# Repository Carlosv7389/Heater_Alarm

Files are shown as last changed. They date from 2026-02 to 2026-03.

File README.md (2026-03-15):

# Heater Alarm
A small and easy to mount device that turns on a heater in order to warm a room at a specified military time.<br>
Heater Alarm

## Table of Contents
1. [Demo](#demo)
2. [Built With](#built-with)
3. [Installation](#installation)
4. [Getting Started](#getting-started)
5. [Usage](#usage)
6. [License](#license)
7. [Acknowledgments](#acknowledgments)

## Demo
A Youtube Short testing the Heater Alarm can be found here: <br>
Here (https://youtube.com/shorts/zdMKMSuSnVs)

## Built With
IDE: VScode with Platformio extension<br>
MCU: ESP32 wroom wifi devkit V1<br>
Serial Monitoring: Tera Term<br>
Platform: Espressif32<br>
Framework: Adruino<br>

## Installation
* To clone this repository:

    ```bash
    git clone https://github.com/Carlosv7389/Heater_Alarm
    ```

* Download VScode at [this link](https://code.visualstudio.com/download)

    * In the "extension" section find platformio 
    <!-- ![install procedure](Project_Media_files/VScode&Platformio.png) -->
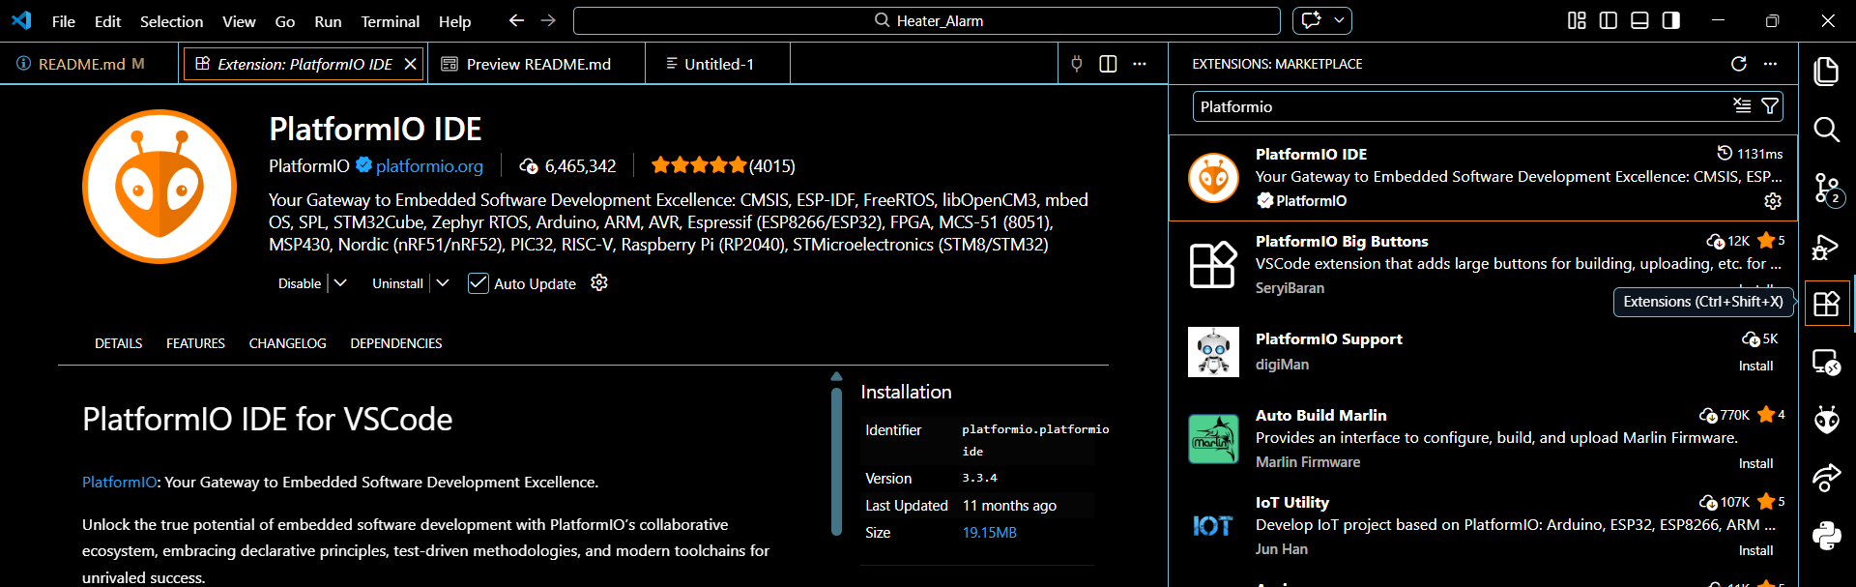
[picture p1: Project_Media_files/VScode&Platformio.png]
Platformio Install screen
    

* Download Tera Term at [this link](https://github.com/TeraTermProject/teraterm/releases)
## Getting Started 
* In VScode, open the folder *Platformio_arduino_wifi*

* Build the circuit shown below:<br>
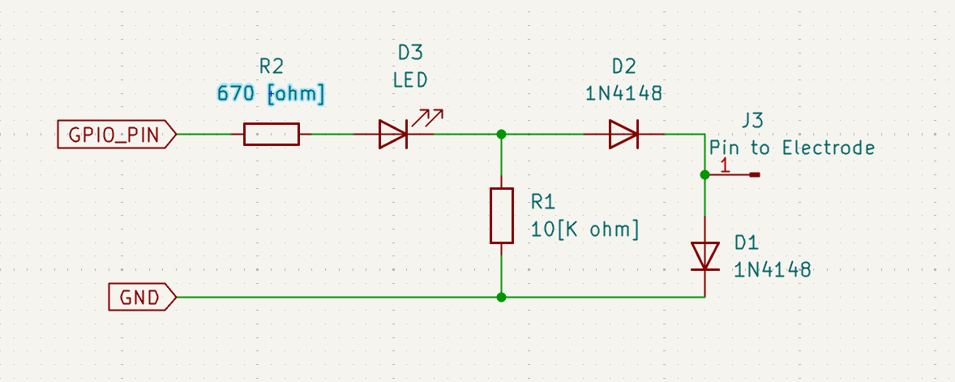
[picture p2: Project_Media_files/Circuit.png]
Capacitive Touch Circuit Schematic
    

* To push the code on to the microcontroller, select all code in *main.cpp* and comment it out. The code from the files in the *lib* folder will be pasted into the bottom of the main file and ran before running the actual main code. <br>

## Usage
* Edit the file *include/secrets.h* to change the ssid and password to your wifi ssid and password.
    ```cpp
    // wifi credentials
    const char *ssid = "change to your SSID";
    const char *password = "change to your password";
    ```

* Check Wifi coverage for your microcontroller by running the code found in *lib/WiFi/WIFIScan.cpp*, run Tera Term and check to see if your WiFi SSID is found in the serial terminal ouput, in the image below, my SSID is "CMCKV9803" and so the device is close enough.<br>
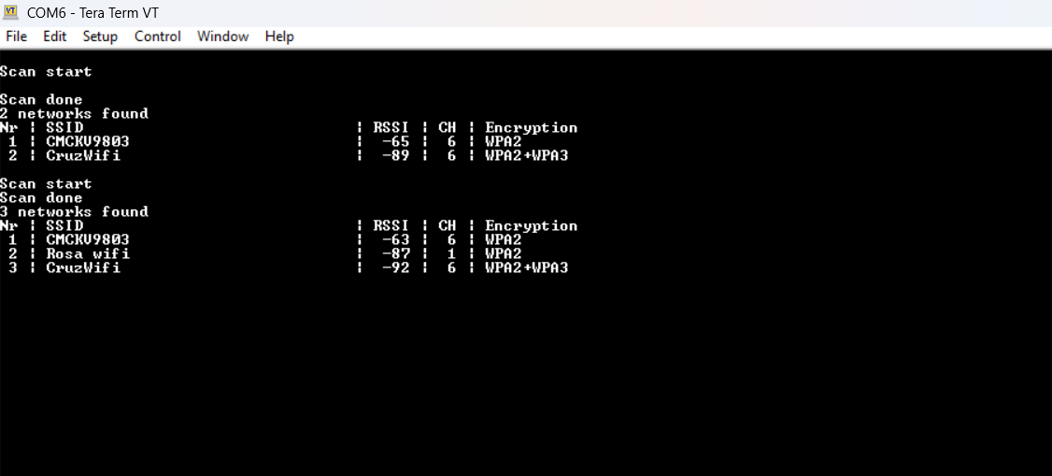
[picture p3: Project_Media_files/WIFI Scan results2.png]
Wifi scan result screen


* Verify circuit by running the code found in *lib/Blink/Blink.cpp*. When the LED transitions from off to on, the heater should turn on as well as seen in the gif below <br>


* Deploy the original code in the *main.cpp* code by uncommenting and changing the main file in order to match your target time, local timezone, and daylight savings offset.
```cpp
const long gmtOffset_sec = (-5)*3600;  // offset for Central Standard Time in seconds (which is "-5 GMT")
const int daylightOffset_sec = 0; // Offset for daylight savings, set to 0 after changing time in spring, set to 3600 when changing time in the fall. 

// Target time to send activation signal (24-hour format) (currently set to 6:45 AM)
const int TARGET_HOUR = 6;    // 6 hours
const int TARGET_MINUTE = 45;  // 45 minutes
const int TARGET_SECOND = 0;   // 0 seconds
```

Tera Term was used as a serial monitor but can't be used simultaneously while uploading code to the microcontroller, make sure its not active when you upload code.
## License
This project is licensed under the MIT License - see the [LICENSE](LICENSE) file for details.

## Acknowledgments
Huge thanks to the channel [Leo's Bag of Tricks](https://www.youtube.com/@leosbagoftricks3732) for making insightful videos on capacitive touch circuits. The circuit shown in the demo is a THT version of the SMD circuit found [here](https://www.youtube.com/watch?v=V0UkCcv2LmQ)

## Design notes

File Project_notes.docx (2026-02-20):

Usefule repo for the ESP32 wroom

ESP32-WROOM-32/esp32-wroom-wifi-devkit-v1_pinout.png at master · devdotnetorg/ESP32-WROOM-32 · GitHub (https://github.com/devdotnetorg/ESP32-WROOM-32/blob/master/esp32-wroom-wifi-devkit-v1_pinout.png)

# Wifi

We either connect to the ESP as an Access point or the ESP connects to the router as a server. For this project we will use esp32 as a server.

From past testing, walls and distance may cause interference in wifi strength, but that does not seem to be an issue for my current configuration.

# RTC

We will use this to keep the time. It will act as a local truth and get updated by an internet clock and we will treat the internet clock as the ground truth

# Low Power Sleep

We will use this module to lower power consumption. The longer we have the sleep, the less reliable the time will be but the trade off is we consume less power

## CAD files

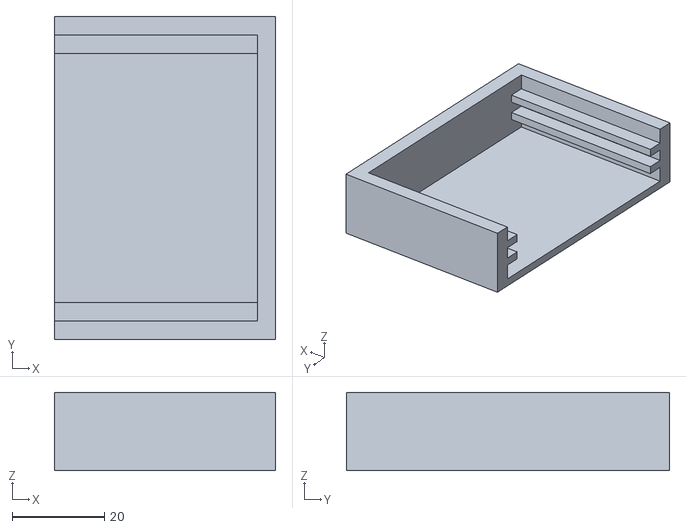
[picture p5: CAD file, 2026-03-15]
CAD Files/EnclosureV3.stl
48.0 x 70.0 x 17.0

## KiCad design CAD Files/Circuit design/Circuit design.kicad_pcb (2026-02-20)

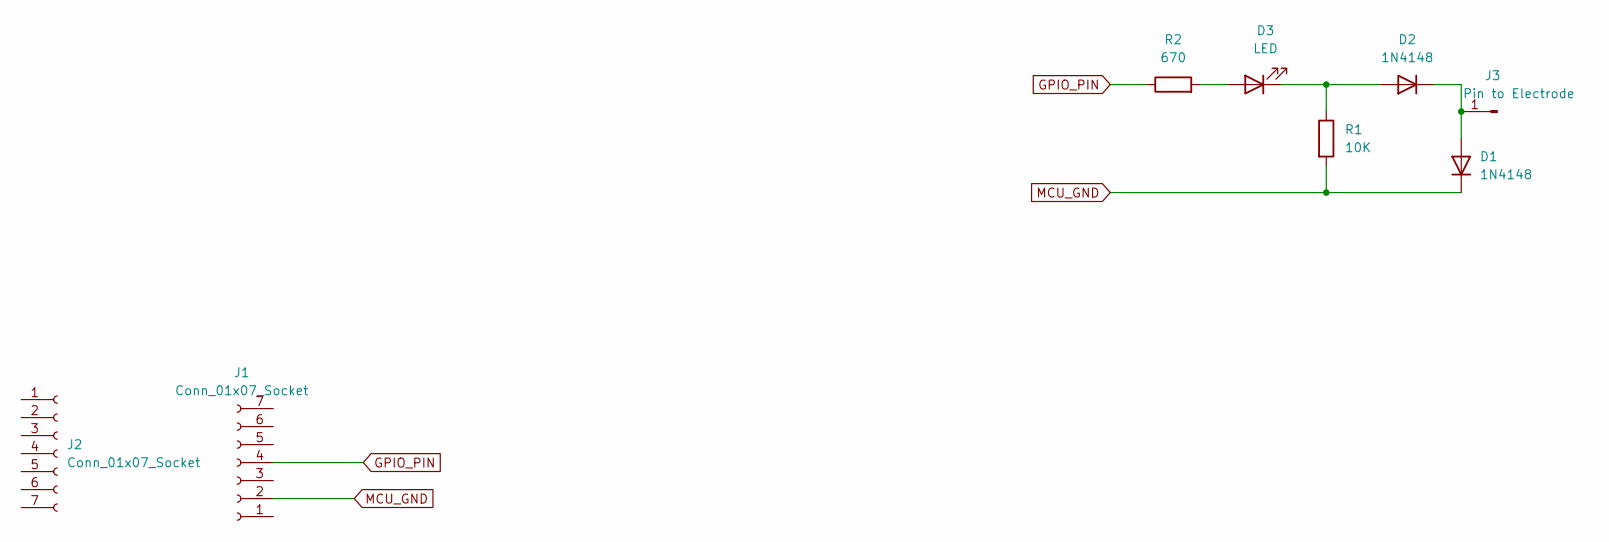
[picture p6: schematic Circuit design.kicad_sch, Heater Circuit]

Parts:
D1, D2: 1N4148; D_DO-35_SOD27_P7.62mm_Horizontal
D3: LED; LED_D3.0mm
J1, J2: Conn_01x07_Socket; PinHeader_1x07_P1.27mm_Vertical
J3: Pin to Electrode; PinHeader_1x01_P1.27mm_Vertical
R1: 10K; R_Axial_DIN0204_L3.6mm_D1.6mm_P5.08mm_Horizontal
R2: 670; R_Axial_DIN0204_L3.6mm_D1.6mm_P5.08mm_Horizontal

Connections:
GPIO_PIN: J1.4, R2.1
MCU_GND: D1.1 (K), J1.2, R1.2
unnamed: D1.2 (A), D2.1 (K), J3.1
unnamed: D2.2 (A), D3.1 (K), R1.1
unnamed: D3.2 (A), R2.2

Board: 2 copper layers, 8 parts (0 on the bottom side), 5 nets, no tracks yet.

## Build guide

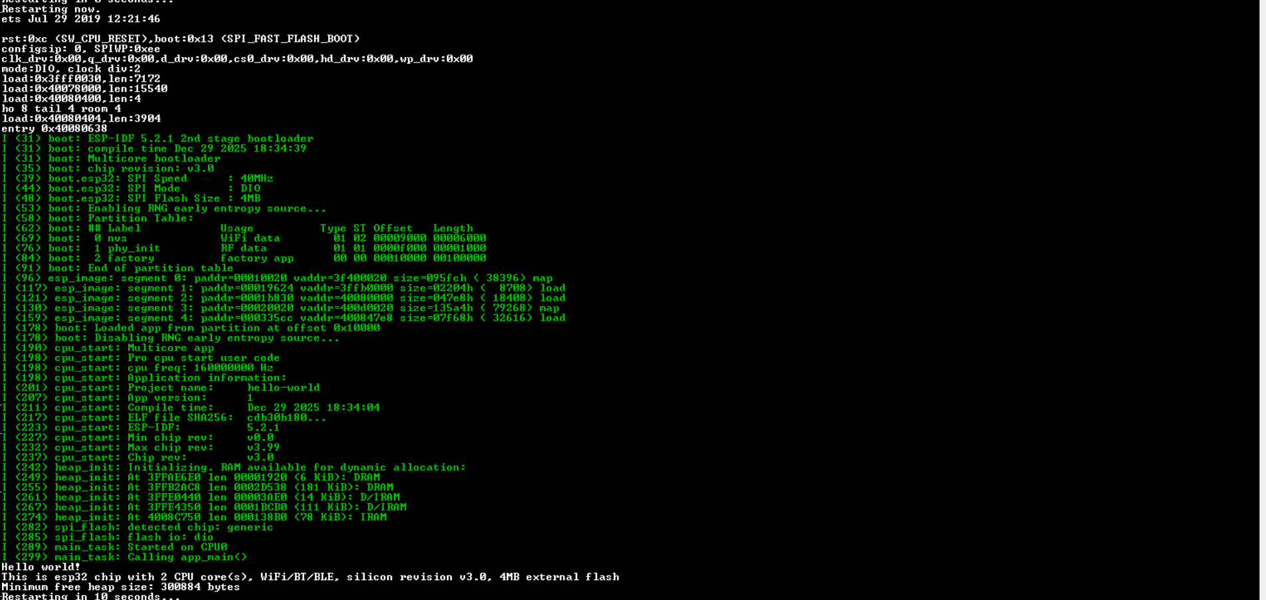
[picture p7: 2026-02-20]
Project_docs/esp32-printout.png

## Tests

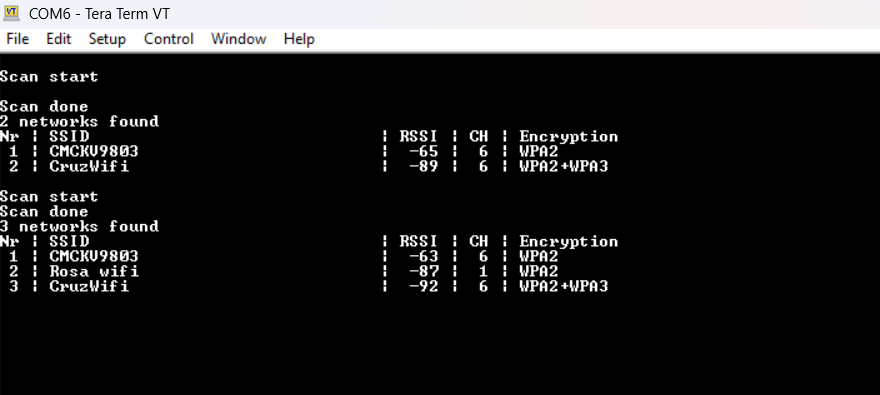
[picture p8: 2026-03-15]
Project_Media_files/WIFI Scan results3.png

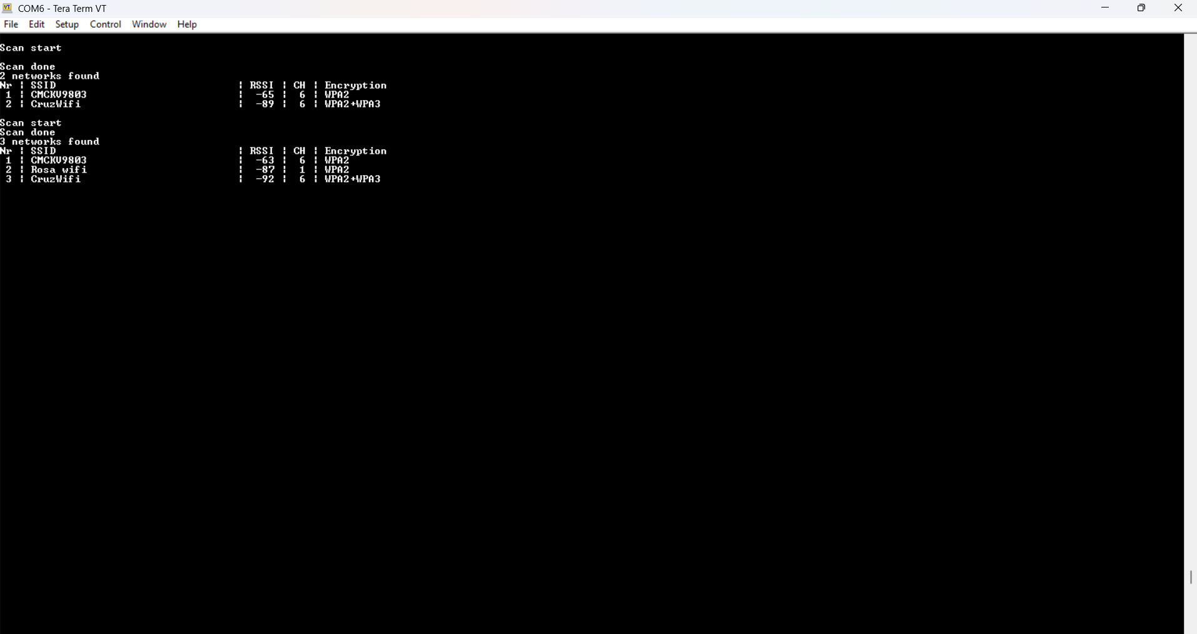
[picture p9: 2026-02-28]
Project_Media_files/WIFI Scan results.png

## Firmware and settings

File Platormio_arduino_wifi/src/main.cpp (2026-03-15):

#include <Arduino.h>
#include <WiFi.h>
#include <time.h>
#include <ESP32Time.h>
#include "secrets.h"
#define Builtin_LED 2 // Indicator LED for the MCU
#define data_line 17 // Pin for sending the activation signal

// NTP Configuration
const char* ntpServer = "pool.ntp.org";
const int gmtOffset_hours = -5; // offset for central standard time (which is "-5 GMT")
const long gmtOffset_sec = gmtOffset_hours*3600;  // offset for Central Standard Time in seconds 
const int daylightOffset_sec = 0; // Offset for daylight savings, set to 0 after changing time in spring, set to 3600 when changing time in the fall. 

// Target time to send activation signal (24-hour format) (currently set to 8:15 AM)
const int TARGET_HOUR = 6;    // 6 hours
const int TARGET_MINUTE = 45;  // 45 minutes
const int TARGET_SECOND = 0;   // 0 seconds

// Deep sleep duration (seconds)
const int CHECK_INTERVAL = 60;  // Number of seconds to check time
ESP32Time rtc(0); 

// RTC Data storage in RTC memory
RTC_DATA_ATTR int bootCount = 0;
RTC_DATA_ATTR time_t lastActivation = 0;

void connectToWiFi() {
  Serial.print("\n\rConnecting to WiFi");
  WiFi.begin(ssid, password);
  
  int attempts = 0;
  while (WiFi.status() != WL_CONNECTED && attempts < 20) {
    delay(800);
    Serial.print(".");
    attempts++;
  }
  
  if (WiFi.status() == WL_CONNECTED) {
    Serial.println("  Connected to WiFi");
  } else {
    Serial.println("  Failed to connect to WiFi");
  }
}
void syncTimeWithNTP() {
  configTime(gmtOffset_sec, daylightOffset_sec, ntpServer);
  
  struct tm timeinfo;
  if (!getLocalTime(&timeinfo)) {
    Serial.println("Failed to obtain time");
    return;
  }
  
  // Set RTC with NTP time
  time_t now;
  time(&now);
  rtc.setTime(now);
  
  Serial.print("\nTime synchronized: ");
  Serial.println(rtc.getTime("%Y-%m-%d %H:%M:%S"));
}

bool shouldActivate() {
  // Get current time from RTC
  int currentHour = rtc.getHour(true);  // 24-hour format
  int currentMinute = rtc.getMinute();
  int currentSecond = rtc.getSecond();
  
  Serial.printf("\rCurrent time: %02d:%02d:%02d\n", 
                currentHour, currentMinute, currentSecond);
  Serial.printf("\rTarget time: %02d:%02d:%02d\n", 
                TARGET_HOUR, TARGET_MINUTE, TARGET_SECOND);
  
  // Check if current time matches target time
  if (currentHour == TARGET_HOUR && 
      currentMinute == TARGET_MINUTE) {
    
    // Prevent multiple activations in the same minute
    time_t now = rtc.getEpoch();
    if ((now - lastActivation) > CHECK_INTERVAL) {
      lastActivation = now;
      return true;
    }
  }
  
  return false;
}

void triggerSignal() {
  Serial.println("\nActivating ...");
  digitalWrite(Builtin_LED, HIGH); 
  digitalWrite(data_line, HIGH);
  delay(500);
  Serial.println("Signal Trigger Complete");
}

void setup() {
  Serial.begin(115200);
  pinMode(Builtin_LED, OUTPUT);      // set the LED pin mode
  pinMode(data_line, OUTPUT);
  bootCount++;
  Serial.printf("\nBoot count: %d", bootCount);

  // Connect to WiFi and sync time (only when needed)
  connectToWiFi();
  
  if (WiFi.status() == WL_CONNECTED) {
    syncTimeWithNTP();
    // Disconnect WiFi to save power
    WiFi.disconnect(true);
    WiFi.mode(WIFI_OFF);
  }
  
  // Check if it's time to activate the heater
  if (shouldActivate()) {
    triggerSignal();
  }
  
  // Prepare for deep sleep
  Serial.printf("\n\rGoing to deep sleep for %d seconds... ", CHECK_INTERVAL);
  
  // Configure wakeup sources for lowest power
  esp_sleep_enable_timer_wakeup(CHECK_INTERVAL * 1000000);
  
  // Enable RTC peripherals to keep time during sleep
  esp_sleep_pd_config(ESP_PD_DOMAIN_RTC_PERIPH, ESP_PD_OPTION_ON);
  
  // Enter deep sleep
  esp_deep_sleep_start();
  
}

void loop(){

}

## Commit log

2026-02-20 Prototype complete, clock reading needs to be more robust
    [Circuit design.kicad_pcb, Circuit design.kicad_sch, Enclosure2.stl]
2026-02-23 bug fixed, rtc no longer restarts when waking from sleep mode.
    [main.cpp]
2026-02-27 adjusted wakeup time to check every minute to avoid double trigger
    [main.cpp]
2026-03-04 Added to ReadME and added more photos
    [Circuit design.kicad_sch]
2026-03-15 Updated enclosure STL, 3D print passed clearance test
    [Enclosure2.stl, EnclosureV3.stl]
2026-03-15 Uploaded correct enclosure stl file
    [EnclosureV3.stl]
